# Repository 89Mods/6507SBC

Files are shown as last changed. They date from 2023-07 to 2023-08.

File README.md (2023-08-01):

# 6507SBC

A 6507-based single-board computer with 128 bytes RAM, 7KiB ROM, I/O, graphics and sound. As an added challenge, it was built with the requirement to not contain any IC larger than DIP-28.

`Hardware` contains the KiCad project files for the SBC itself, as well as the adapter board for the supported SPI peripherals.

`Programs` are programs written to test various features of the SBC.

`Verilog` contains a basic Verilog implementation of the 6507, and the pixel LCD peripheral. Used during software development when ROM swapping became too tedious. Doesn’t implement undocumented instructions or decimal mode.

For more information, see the writeup [on my website](https://tholin.dev/6507/).

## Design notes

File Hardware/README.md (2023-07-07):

# Hardware

Here are the KiCad projects for the computer! BOMs and Gerbers are in the respective 'production' folder of each KiCad project.

The 'expansion board' is a board that plugs directly into a header on the SBC, and adapts some of its I/O ports to two supported SPI peripherals, which can then be driven in software. One is a 25Qxx flash ROM for additional data storage (7KiB isn’t a lot), and the other a pixel LCD (ST7565), which forms the graphics output of the computer.

They can be found for cheap on AliExpress. I got [this one](https://aliexpress.com/item/1005001621784395.html).

However, in the absence of this, the SBC also has a header for a regular character LCD. If this is not required, components J5, RV1 and R19 can be omitted.

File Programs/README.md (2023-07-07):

# Programs

Here are various programs to test the computer’s hardware, and stress the CPU and Memory (mandelbrot renderer). Due to the memory map of the system, the ROM binaries must be padded with 1024 bytes of 0s at the beginning. The PadROM script written in Java takes care of this.

Every program is contained in its own directory, which also contains a bash script to automatically run all the commands to build the program. cc65 is required to assemble the programs.

<table>
    <tr>
        <th>Name</th>
        <th>Description</th>
    </tr>
    <tr>
        <td>board_test</td>
        <td>Just blinks some LEDs, makes beepboops and puts text on the character LCD.</td>
    </tr>
    <tr>
        <td>mandel</td>
        <td>Mandelbrot set renderer. Makes use of the pixel LCD.</td>
    </tr>
    <tr>
        <td>psg_test</td>
        <td>Tests the sound output by playing some tunes.</td>
    </tr>
    <tr>
        <td>spi_lcd_test</td>
        <td>Copies a bitmap image onto the SPI LCD for testing purposes.</td>
    </tr>
    <tr>
        <td>spi_rom_test</td>
        <td>Plays a VGM file from the SPI ROM. Code is a bit of a mess due to containing dummy subroutines to make the timing of the notes work out.</td>
    </tr>
</table>

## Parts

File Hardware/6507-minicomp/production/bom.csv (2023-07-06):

Designator | Footprint | Quantity | Value | LCSC Part #
BZ1 | Buzzer_12x9.5RM7.6 | 1 | Piezo Speaker
C1, C2, C3, C4 | CP_Radial_D6.3mm_P2.50mm | 4 | 10µF
D1, D2, D3 | D_A-405_P7.62mm_Horizontal | 3 | D
D4, D5, D6, D7 | LED_D3.0mm | 4 | LED
J1 | TerminalBlock_bornier-2_P5.08mm | 1 | Screw_Terminal_01x02
J2 | PinHeader_1x08_P2.54mm_Vertical | 1 | Conn_01x08_Female
J3 | PinHeader_1x11_P2.54mm_Vertical | 1 | Conn_01x11
J5 | PinHeader_1x16_P2.54mm_Vertical | 1 | Conn_01x16_Female
R1, R4, R7 | R_Axial_DIN0204_L3.6mm_D1.6mm_P7.62mm_Horizontal | 3 | 10K
R10, R11, R12, R14, R15, R16, R2, R3, R8, R9 | R_Axial_DIN0204_L3.6mm_D1.6mm_P7.62mm_Horizontal | 10 | 7.2K
R13, R17, R18 | R_Axial_DIN0204_L3.6mm_D1.6mm_P7.62mm_Horizontal | 3 | 4.7K
R19 | R_Axial_DIN0204_L3.6mm_D1.6mm_P7.62mm_Horizontal | 1 | 1K
R5 | R_Axial_DIN0204_L3.6mm_D1.6mm_P7.62mm_Horizontal | 1 | 200K
R6 | R_Axial_DIN0204_L3.6mm_D1.6mm_P7.62mm_Horizontal | 1 | 100
RV1 | Potentiometer_ACP_CA9-V10_Vertical | 1 | 10K
SW1, SW2 | SW_PUSH_6mm | 2 | SW_Push
U1, U2 | DIP-14_W7.62mm | 2 | 74LS08
U10, U11, U12 | DIP-24_W15.24mm | 3 | DS8212D
U3 | DIP-14_W7.62mm | 1 | 74HC04
U4 | DIP-28_W15.24mm | 1 | 6507
U5 | DIP-16_W7.62mm | 1 | 74LS163
U6 | DIP-8_W7.62mm | 1 | LM358
U7 | DIP-16_W7.62mm | 1 | SN76489
U8 | DIP-24_W15.24mm | 1 | MCM6810
U9 | DIP-28_W15.24mm | 1 | 28C256
X1 | Oscillator_DIP-14 | 1 | ACO-16.0MHz

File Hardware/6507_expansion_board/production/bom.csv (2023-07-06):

Designator | Footprint | Quantity | Value | LCSC Part #
C1 | 1206 | 1 | 100nF
C2 | 1206 | 1 | 100nF
D1 | 0805 | 1 | LED
D2 | 0805 | 1 | D
J1 | PinHeader_1x11_P2.54mm_Vertical | 1 | Conn_01x11
J2 | PinHeader_1x13_P2.54mm_Vertical | 1 | Conn_01x13
R1 | 2010 | 1 | 1K
R10 | 2010 | 1 | 1K
R11 | 2010 | 1 | 1K
R12 | 2010 | 1 | 1K
R13 | 2010 | 1 | 1K
R14 | 2010 | 1 | 1K
R2 | 2010 | 1 | 1K
R3 | 2010 | 1 | 1K
R4 | 2010 | 1 | 1K
R6 | 2010 | 1 | 1K
R7 | 2010 | 1 | 1K
R8 | 2010 | 1 | 1K
R9 | 2010 | 1 | 1K
U1 | DIP-8_W7.62mm_LongPads | 1 | MX25L1005
U2 | SOT-223-3_TabPin2 | 1 | AMS1117

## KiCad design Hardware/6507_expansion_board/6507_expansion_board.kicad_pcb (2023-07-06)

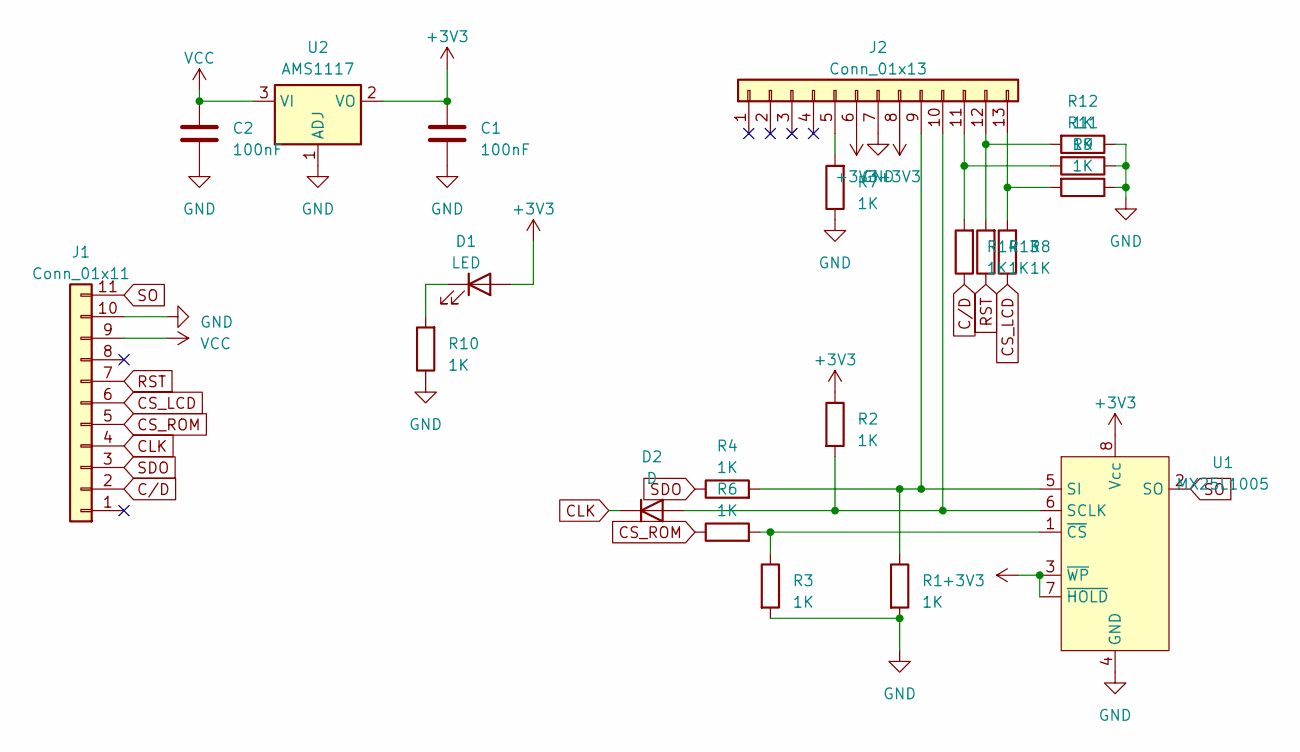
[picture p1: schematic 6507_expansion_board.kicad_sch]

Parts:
C1, C2: 100nF; C_1206_3216Metric
D1: LED; LED_0805_2012Metric
D2: D; D_0805_2012Metric
J1: Conn_01x11; PinHeader_1x11_P2.54mm_Vertical
J2: Conn_01x13; PinHeader_1x13_P2.54mm_Vertical
R1, R2, R3, R4, R6, R7, R8, R9, R10, R11, R12, R13, R14: 1K; R_2010_5025Metric_Pad1.40x2.65mm_HandSolder
U1: MX25L1005; DIP-8_W7.62mm_LongPads
U2: AMS1117; SOT-223-3_TabPin2

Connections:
+3V3: C1.1, D1.2 (A), J2.6, J2.8, R2.1, U1.3 (~WP), U1.7 (~HOLD), U1.8 (Vcc), U2.2 (VO)
CLK: D2.1 (K), J1.4
CS_LCD: J1.6, R8.1
CS_ROM: J1.5, R6.1
C/D: J1.2, R14.1
GND: C1.2, C2.2, J1.10, J2.7, R1.2, R3.2, R7.1, R9.1, R10.1, R11.1, R12.1, U1.4 (GND), U2.1 (ADJ)
unnamed: D1.1 (K), R10.2
unnamed: D2.2 (A), J2.10, R2.2, U1.6 (SCLK)
unnamed: J2.5, R7.2
unnamed: J2.9, R1.1, R4.2, U1.5 (SI)
unnamed: J2.11, R11.2, R14.2
unnamed: J2.12, R12.2, R13.2
unnamed: J2.13, R8.2, R9.2
unnamed: R3.1, R6.2, U1.1 (~CS)
RST: J1.7, R13.1
SDO: J1.3, R4.1
SO: J1.11, U1.2 (SO)
VCC: C2.1, J1.9, U2.3 (VI)

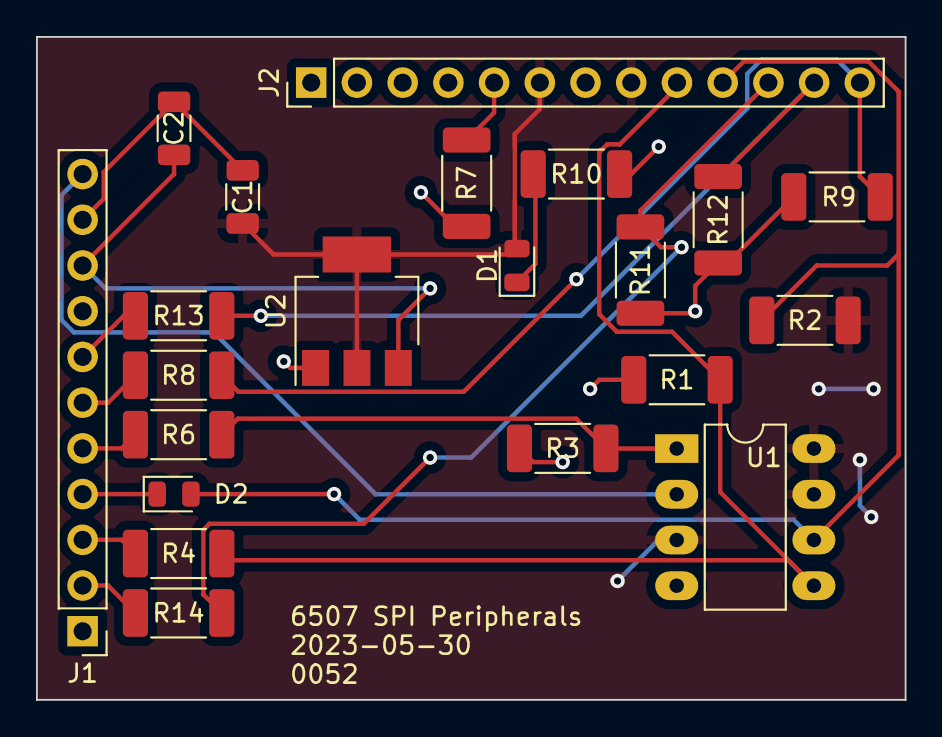
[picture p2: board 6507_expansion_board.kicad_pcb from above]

Board: 2 copper layers, 48.3 x 36.8 mm, 21 parts (0 on the bottom side), 18 nets.

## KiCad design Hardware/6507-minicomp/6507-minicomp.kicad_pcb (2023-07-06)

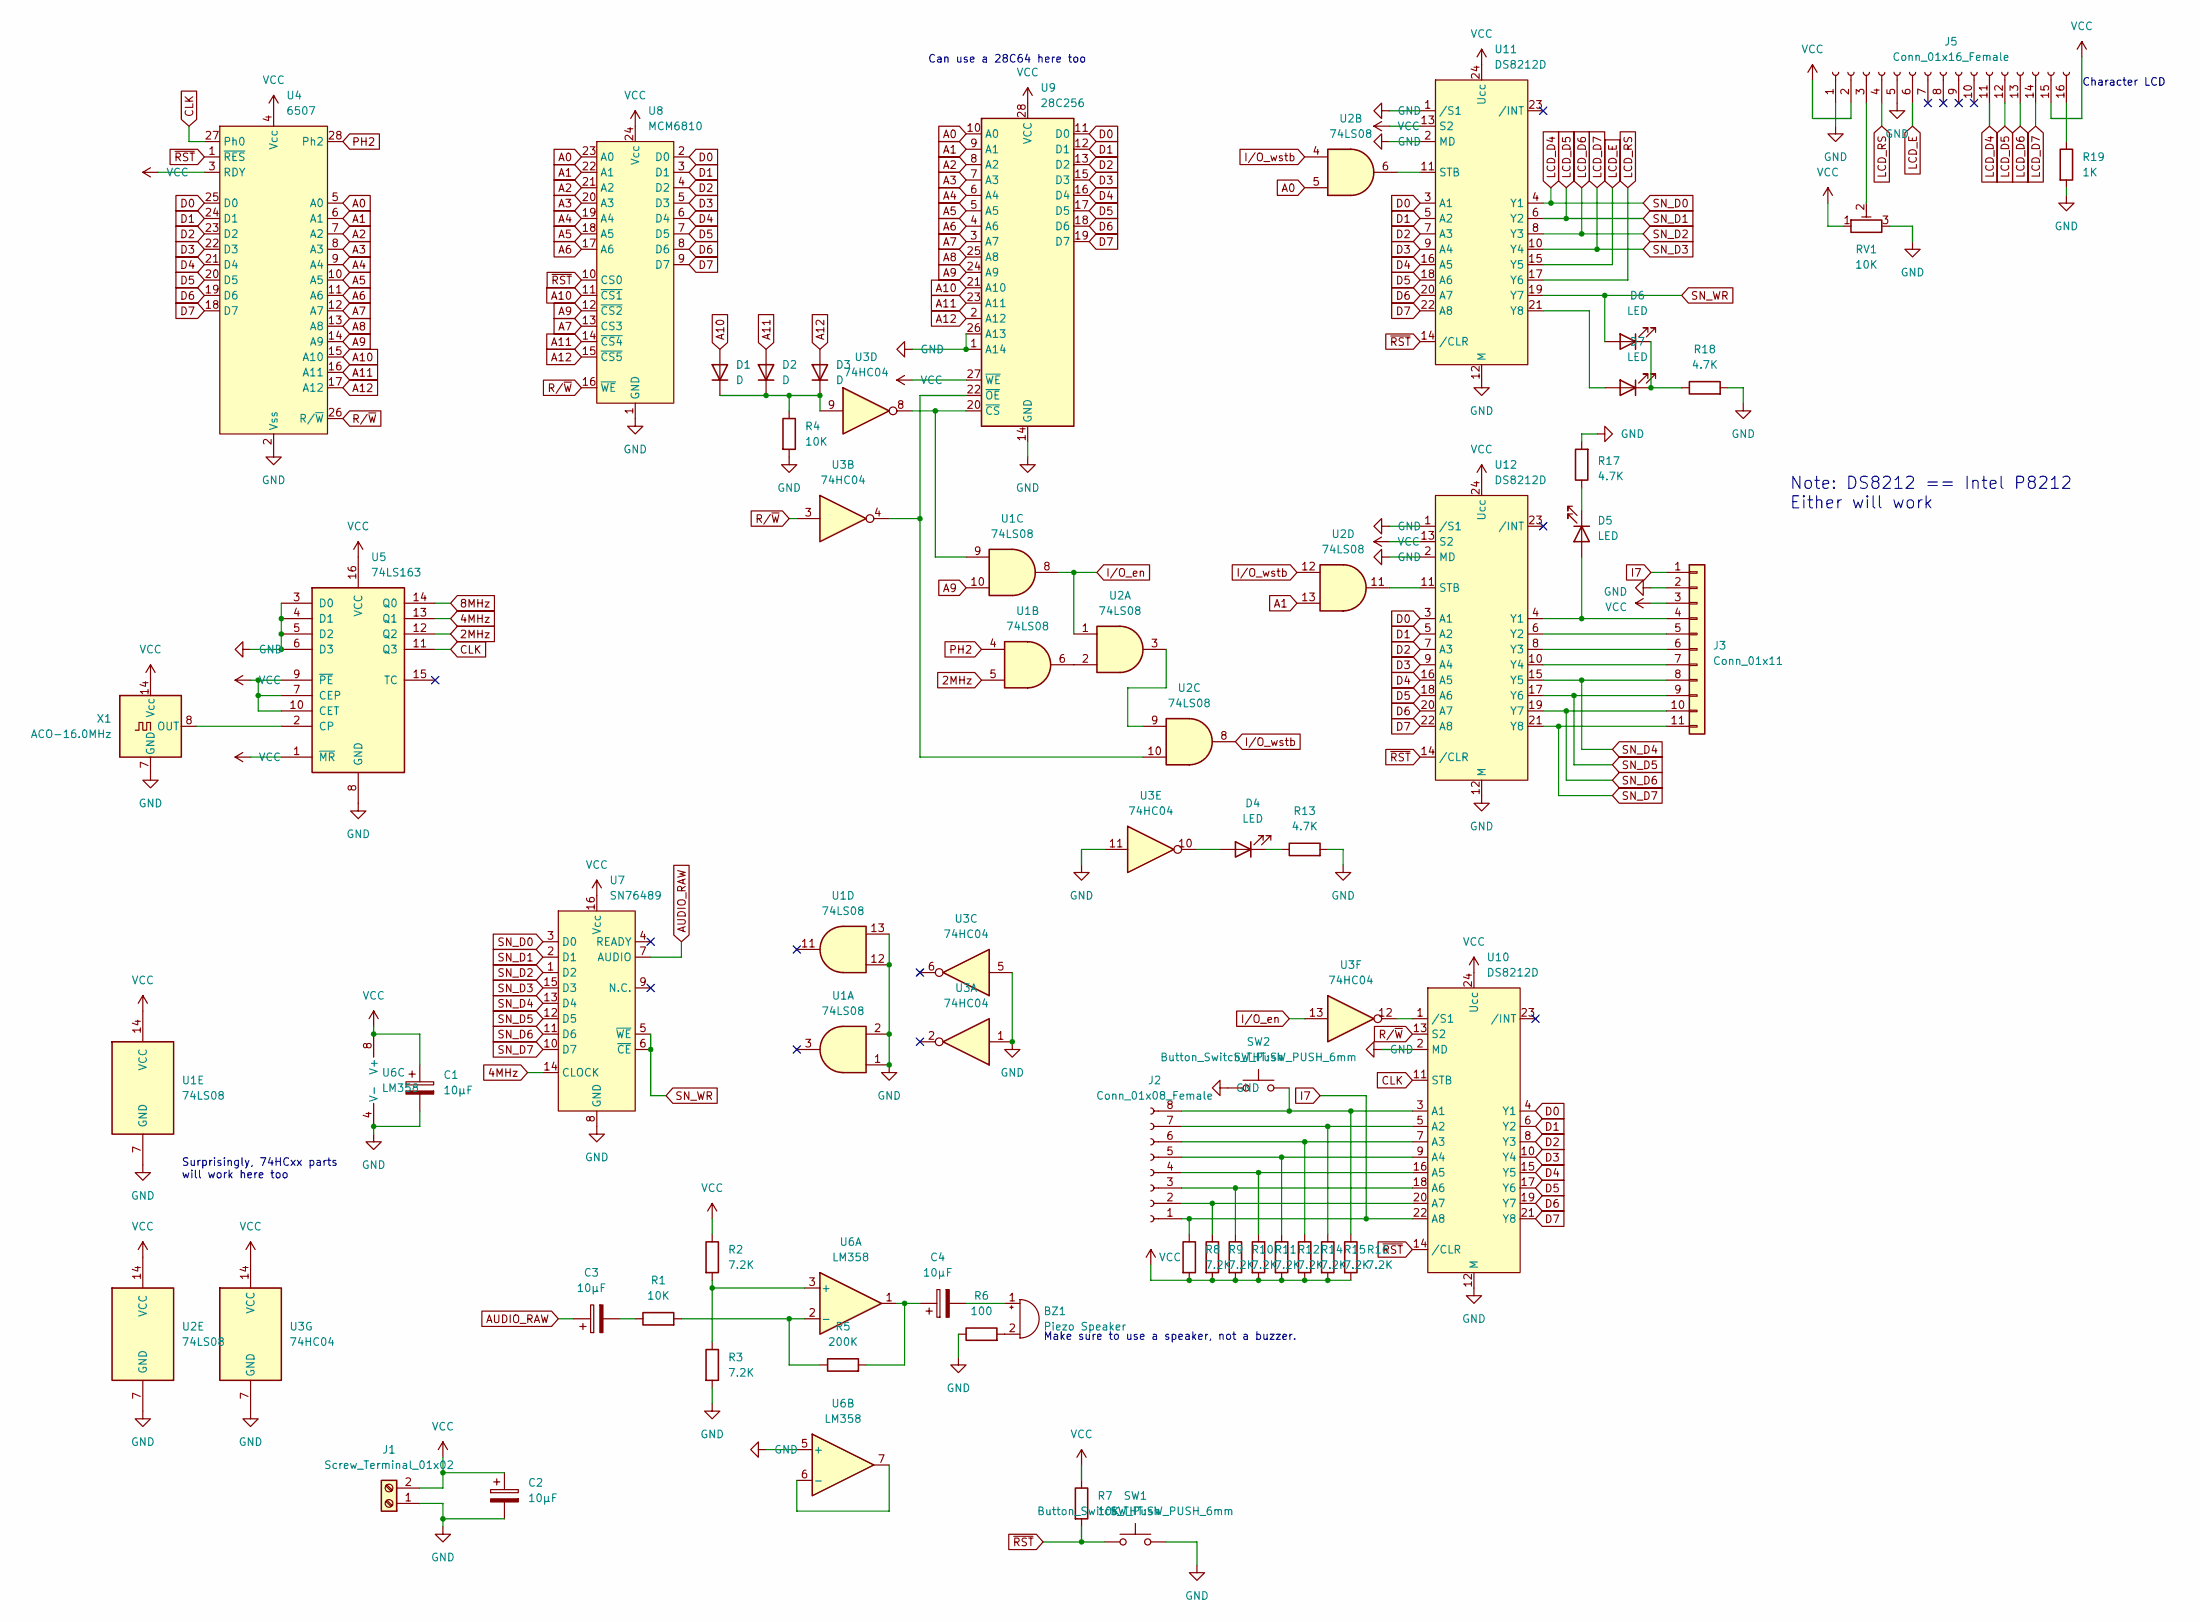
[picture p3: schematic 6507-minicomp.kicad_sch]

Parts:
BZ1: Piezo Speaker; Buzzer_12x9.5RM7.6
C1, C2, C3, C4: 10µF; CP_Radial_D6.3mm_P2.50mm
D1, D2, D3: D; D_A-405_P7.62mm_Horizontal
D4, D5, D6, D7: LED; LED_D3.0mm
J1: Screw_Terminal_01x02; TerminalBlock_bornier-2_P5.08mm
J2: Conn_01x08_Female; PinHeader_1x08_P2.54mm_Vertical
J3: Conn_01x11; PinHeader_1x11_P2.54mm_Vertical
J5: Conn_01x16_Female; PinHeader_1x16_P2.54mm_Vertical
R1, R4, R7: 10K; R_Axial_DIN0204_L3.6mm_D1.6mm_P7.62mm_Horizontal
R2, R3, R8, R9, R10, R11, R12, R14, R15, R16: 7.2K; R_Axial_DIN0204_L3.6mm_D1.6mm_P7.62mm_Horizontal
R5: 200K; R_Axial_DIN0204_L3.6mm_D1.6mm_P7.62mm_Horizontal
R6: 100; R_Axial_DIN0204_L3.6mm_D1.6mm_P7.62mm_Horizontal
R13, R17, R18: 4.7K; R_Axial_DIN0204_L3.6mm_D1.6mm_P7.62mm_Horizontal
R19: 1K; R_Axial_DIN0204_L3.6mm_D1.6mm_P7.62mm_Horizontal
RV1: 10K; Potentiometer_ACP_CA9-V10_Vertical
SW1, SW2: SW_Push; SW_PUSH_6mm
U1, U2: 74LS08; DIP-14_W7.62mm
U3: 74HC04; DIP-14_W7.62mm
U4: 6507; DIP-28_W15.24mm
U5: 74LS163; DIP-16_W7.62mm
U6: LM358; DIP-8_W7.62mm
U7: SN76489; DIP-16_W7.62mm
U8: MCM6810; DIP-24_W15.24mm
U9: 28C256; DIP-28_W15.24mm
U10, U11, U12: DS8212D; DIP-24_W15.24mm
X1: ACO-16.0MHz; Oscillator_DIP-14

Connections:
2MHz: U1.5, U5.12 (Q2)
4MHz: U5.13 (Q1), U7.14 (CLOCK)
8MHz: U5.14 (Q0)
A0: U2.5, U4.5 (A0), U8.23 (A0), U9.10 (A0)
A1: U2.13, U4.6 (A1), U8.22 (A1), U9.9 (A1)
A2: U4.7 (A2), U8.21 (A2), U9.8 (A2)
A3: U4.8 (A3), U8.20 (A3), U9.7 (A3)
A4: U4.9 (A4), U8.19 (A4), U9.6 (A4)
A5: U4.10 (A5), U8.18 (A5), U9.5 (A5)
A6: U4.11 (A6), U8.17 (A6), U9.4 (A6)
A7: U4.12 (A7), U8.13 (CS3), U9.3 (A7)
A8: U4.13 (A8), U9.25 (A8)
A9: U1.10, U4.14 (A9), U8.12 (~CS2), U9.24 (A9)
A10: D1.2 (A), U4.15 (A10), U8.11 (~CS1), U9.21 (A10)
A11: D2.2 (A), U4.16 (A11), U8.14 (~CS4), U9.23 (A11)
A12: D3.2 (A), U4.17 (A12), U8.15 (~CS5), U9.2 (A12)
AUDIO_RAW: C3.1, U7.7 (AUDIO)
CLK: U4.27 (Ph0), U5.11 (Q3), U10.11 (STB)
D0: U4.25 (D0), U8.2 (D0), U9.11 (D0), U10.4 (Y1), U11.3 (A1), U12.3 (A1)
D1: U4.24 (D1), U8.3 (D1), U9.12 (D1), U10.6 (Y2), U11.5 (A2), U12.5 (A2)
D2: U4.23 (D2), U8.4 (D2), U9.13 (D2), U10.8 (Y3), U11.7 (A3), U12.7 (A3)
D3: U4.22 (D3), U8.5 (D3), U9.15 (D3), U10.10 (Y4), U11.9 (A4), U12.9 (A4)
D4: U4.21 (D4), U8.6 (D4), U9.16 (D4), U10.15 (Y5), U11.16 (A5), U12.16 (A5)
D5: U4.20 (D5), U8.7 (D5), U9.17 (D5), U10.17 (Y6), U11.18 (A6), U12.18 (A6)
D6: U4.19 (D6), U8.8 (D6), U9.18 (D6), U10.19 (Y7), U11.20 (A7), U12.20 (A7)
D7: U4.18 (D7), U8.9 (D7), U9.19 (D7), U10.21 (Y8), U11.22 (A8), U12.22 (A8)
GND: C1.2, C2.2, J1.1, J3.2, J5.1, J5.5, R3.2, R4.2, R6.1, R13.2, R17.2, R18.2, R19.2, RV1.3, SW1.2, SW2.1, U1.1, U1.2, U1.7 (GND), U1.12, U1.13, U2.7 (GND), U3.1, U3.5, U3.7 (GND), U3.11, U4.2 (Vss), U5.3 (D0), U5.4 (D1), U5.5 (D2), U5.6 (D3), U5.8 (GND), U6.4 (V-), U6.5 (+), U7.8 (GND), U8.1 (GND), U9.1 (A14), U9.14 (GND), U9.26 (A13), U10.2 (MD), U10.12 (M), U11.1 (/S1), U11.2 (MD), U11.12 (M), U12.1 (/S1), U12.2 (MD), U12.12 (M), X1.7 (GND)
I7: J2.1, J3.1, R8.1, U10.22 (A8)
I/O_en: U1.8, U2.1, U3.13
I/O_wstb: U2.4, U2.8, U2.12
LCD_D4: J5.11, U7.3 (D0), U11.4 (Y1)
LCD_D5: J5.12, U7.2 (D1), U11.6 (Y2)
LCD_D6: J5.13, U7.1 (D2), U11.8 (Y3)
LCD_D7: J5.14, U7.15 (D3), U11.10 (Y4)
LCD_E: J5.6, U11.15 (Y5)
LCD_RS: J5.4, U11.17 (Y6)
unnamed: BZ1.2 (+), R6.2
unnamed: BZ1.1 (-), C4.2
unnamed: C3.2, R1.1
unnamed: C4.1, R5.2, U6.1
unnamed: D1.1 (K), D2.1 (K), D3.1 (K), R4.1, U3.9
unnamed: D4.2 (A), U3.10
unnamed: D4.1 (K), R13.1
unnamed: D5.2 (A), J3.4, U12.4 (Y1)
unnamed: D5.1 (K), R17.1
unnamed: D6.1 (K), D7.1 (K), R18.1
unnamed: D7.2 (A), U11.21 (Y8)
unnamed: J2.2, R9.1, U10.20 (A7)
unnamed: J2.3, R10.1, U10.18 (A6)
unnamed: J2.4, R11.1, U10.16 (A5)
unnamed: J2.5, R12.1, U10.9 (A4)
unnamed: J2.6, R14.1, U10.7 (A3)
unnamed: J2.7, R15.1, U10.5 (A2)
unnamed: J2.8, R16.1, SW2.2, U10.3 (A1)
unnamed: J3.5, U12.6 (Y2)
unnamed: J3.6, U12.8 (Y3)
unnamed: J3.7, U12.10 (Y4)
unnamed: J5.3, RV1.2
unnamed: J5.16, R19.1
unnamed: U1.6, U2.2
unnamed: U2.3, U2.9
unnamed: U5.2 (CP), X1.8 (OUT)
unnamed: R2.2, R3.1, U6.3 (+)
unnamed: R1.2, R5.1, U6.2 (-)
unnamed: U6.6 (-), U6.7
unnamed: U1.9, U3.8, U9.20 (~CS)
unnamed: U2.10, U3.4, U9.22 (~OE)
unnamed: U3.12, U10.1 (/S1)
unnamed: U2.6, U11.11 (STB)
unnamed: U2.11, U12.11 (STB)
PH2: U1.4, U4.28 (Ph2)
R/~W: U3.3, U4.26 (R/~W), U8.16 (~WE), U10.13 (S2)
SN_D4: J3.8, U7.13 (D4), U12.15 (Y5)
SN_D5: J3.9, U7.12 (D5), U12.17 (Y6)
SN_D6: J3.10, U7.11 (D6), U12.19 (Y7)
SN_D7: J3.11, U7.10 (D7), U12.21 (Y8)
SN_WR: D6.2 (A), U7.5 (~WE), U7.6 (~CE), U11.19 (Y7)
VCC: C1.1, C2.1, J1.2, J3.3, J5.2, J5.15, R2.1, R7.1, R8.2, R9.2, R10.2, R11.2, R12.2, R14.2, R15.2, R16.2, RV1.1, U1.14 (VCC), U2.14 (VCC), U3.14 (VCC), U4.3 (RDY), U4.4 (Vcc), U5.1 (~MR), U5.7 (CEP), U5.9 (~PE), U5.10 (CET), U5.16 (VCC), U6.8 (V+), U7.16 (Vcc), U8.24 (Vcc), U9.27 (~WE), U9.28 (VCC), U10.24 (Ucc), U11.13 (S2), U11.24 (Ucc), U12.13 (S2), U12.24 (Ucc), X1.14 (Vcc)
~RST: R7.2, SW1.1, U4.1 (~RES), U8.10 (CS0), U10.14 (/CLR), U11.14 (/CLR), U12.14 (/CLR)

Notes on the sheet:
Character LCD
Make sure to use a speaker, not a buzzer.
Note: DS8212 == Intel P8212 Either will work
Surprisingly, 74HCxx parts will work here too
Can use a 28C64 here too

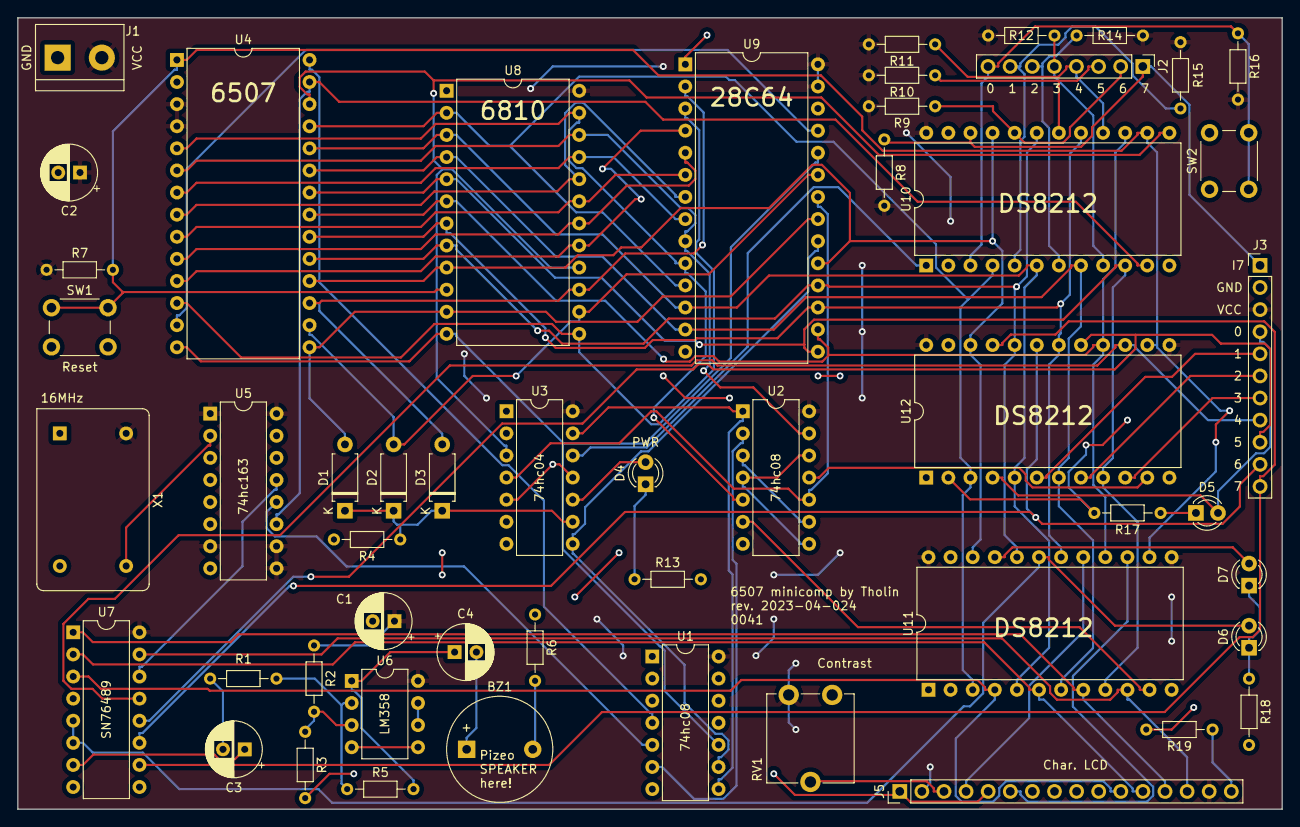
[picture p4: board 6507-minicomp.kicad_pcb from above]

Board: 2 copper layers, 145.3 x 90.9 mm, 51 parts (0 on the bottom side), 78 nets.

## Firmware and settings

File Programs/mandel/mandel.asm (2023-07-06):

.feature string_escapes
.feature org_per_seg
.feature c_comments

PORT1_OUT  = $0201
PORT2_OUT  = $0202
PORT_IN    = $0208

mem_start = $80
port1_shadow = mem_start+1
port2_shadow = mem_start+2
counter = mem_start+6
temp0 = mem_start+7
temp1 = mem_start+8

min00 = mem_start+9
min01 = mem_start+10
min02 = mem_start+11
min03 = mem_start+12
min10 = mem_start+13
min11 = mem_start+14
min12 = mem_start+15
min13 = mem_start+16
mres0 = mem_start+17
mres1 = mem_start+18
mres2 = mem_start+19
mres3 = mem_start+20
mres4 = mem_start+21
mres5 = mem_start+22
mres6 = mem_start+23
mres7 = mem_start+24
mtemp0 = mem_start+25
mtemp1 = mem_start+26
mtemp2 = mem_start+27
mtemp3 = mem_start+28
mtemp4 = mem_start+29
mtemp5 = mem_start+30
mtemp6 = mem_start+31

loopi0 = mem_start+32
loopi1 = mem_start+33
col_buff = mem_start+34
xpos = mem_start+35
ypos = mem_start+36

; Mandel vars
C1 = mem_start+40
C2 = mem_start+44
C3 = mem_start+48
C4 = mem_start+52
C_IM = mem_start+56
C_RE = mem_start+60
MAN_X = mem_start+64
MAN_Y = mem_start+68
MAN_XX = mem_start+72
MAN_YY = mem_start+76
ITERATION = mem_start+80

rem0 = mem_start+81
rem1 = mem_start+82
rem2 = mem_start+83
rem3 = mem_start+84

width = 128
height = 64
total_loops = 8192

; Constants
W_D2 = 64
H_D2 = 32

ZOOM = 16000000
RE = 0
IMAG = 0
MAX_ITER = 128

.segment "CODE"
NMI:
	rti
IRQ:
	rti
RESET:
	ldx #$FF
	txs
	lda #0
	sta mem_start
	cld
	clv
	
	lda #%00001100
	sta PORT2_OUT
	sta port2_shadow
	
	lda #%01010000
	sta PORT1_OUT
	sta port1_shadow
	jsr init_psg
	jsr reset_lcd
	
	jsr clear_lcd
	jsr lcd_select
	
mandel_calc_constants_c1:
	; res = 4 / width
	lda #0
	sta min00
	sta min01
	sta min02
	lda #4
	sta min03
	lda #0
	sta min10
	sta min11
	sta min12
	lda #width
	sta min13
	jsr div_fixed
	; C1 = res * ZOOM
	lda mres0
	sta min00
	lda mres1
	sta min01
	lda mres2
	sta min02
	lda mres3
	sta min03
	lda #ZOOM&255
	sta min10
	lda #(ZOOM>>8)&255
	sta min11
	lda #(ZOOM>>16)&255
	sta min12
	lda #(ZOOM>>24)&255
	sta min13
	jsr mul_fixed
	lda mres0
	sta C1
	sta min10
	lda mres1
	sta C1+1
	sta min11
	lda mres2
	sta C1+2
	sta min12
	lda mres3
	sta C1+3
	sta min13
	; C2 = W_D2 * C1
	lda #0
	sta min00
	sta min01
	sta min02
	lda #W_D2
	sta min03
	jsr mul_fixed
	lda mres0
	sta C2
	lda mres1
	sta C2+1
	lda mres2
	sta C2+2
	lda mres3
	sta C2+3
	
mandel_calc_constants_c4:
	; res = 2 / height
	lda #0
	sta min00
	sta min01
	sta min02
	lda #2
	sta min03
	lda #0
	sta min10
	sta min11
	sta min12
	lda #height
	sta min13
	jsr div_fixed
	; C4 = res * ZOOM
	lda mres0
	sta min00
	lda mres1
	sta min01
	lda mres2
	sta min02
	lda mres3
	sta min03
	lda #ZOOM&255
	sta min10
	lda #(ZOOM>>8)&255
	sta min11
	lda #(ZOOM>>16)&255
	sta min12
	lda #(ZOOM>>24)&255
	sta min13
	jsr mul_fixed
	lda mres0
	sta C4
	sta min10
	lda mres1
	sta C4+1
	sta min11
	lda mres2
	sta C4+2
	sta min12
	lda mres3
	sta C4+3
	sta min13
	; C3 = H_D2 * C4
	lda #0
	sta min00
	sta min01
	sta min02
	lda #H_D2
	sta min03
	jsr mul_fixed
	lda mres0
	sta C3
	lda mres1
	sta C3+1
	lda mres2
	sta C3+2
	lda mres3
	sta C3+3
	
	lda #0
	sta loopi0
	sta loopi1
	lda #7
	sta ypos
	jsr lcd_sety
	lda #width
	sta xpos
mandel_loop_main:
	jsr lcd_unselect
	nop
	nop
	nop
	nop
	nop
	nop
	nop
	nop
	jsr lcd_select
	nop
	nop
	nop
	nop
	nop
	nop
	nop
	nop
	lda loopi0
	and #7
	beq col_loop_done
	jmp col_loop_not_done
col_loop_done:
	lda xpos
	jsr lcd_setx
	lda col_buff
	jsr lcd_data
	
	dec xpos
	lda #255
	cmp xpos
	bne not_at_end_of_row
	jsr lcd_unselect
	nop
	nop
	nop
	nop
	jsr boop
	jsr lcd_select
	nop
	nop
	nop
	nop
	lda #width-1
	sta xpos
	jsr lcd_setx
	dec ypos
	lda ypos
	jsr lcd_sety
not_at_end_of_row:
	lda xpos
	jsr lcd_setx
	lda #0
	sta col_buff
	
	; Recompute C_RE
	; res = col * C1
	lda #0
	sta min00
	sta min01
	sta min02
	lda xpos
	eor #127
	sta min03
	lda C1
	sta min10
	lda C1+1
	sta min11
	lda C1+2
	sta min12
	lda C1+3
	sta min13
	jsr mul_fixed
	; res = res + RE
	clc
	lda mres0
	adc #RE&255
	sta mres0
	lda mres1
	adc #(RE>>8)&255
	sta mres1
	lda mres2
	adc #(RE>>16)&255
	sta mres2
	lda mres3
	adc #(RE>>24)&255
	sta mres3
	; C_RE = res - C2
	sec
	lda mres0
	sbc C2
	sta C_RE
	lda mres1
	sbc C2+1
	sta C_RE+1
	lda mres2
	sbc C2+2
	sta C_RE+2
	lda mres3
	sbc C2+3
	sta C_RE+3
	
col_loop_not_done:
	lda xpos
	jsr lcd_setx
	lda ypos
	jsr lcd_sety
	lda loopi0
	and #7
	tax
	lda col_buff
	ora bit_mask,X
	jsr lcd_data
	
	; Compute C_IM
	; res = row * C4
	lda #0
	sta min00
	sta min01
	sta min02
	
	lda ypos
	eor #7
	asl
	asl
	asl
	sta temp0
	lda loopi0
	and #7
	clc
	adc temp0
	sta min03
	
	lda C4
	sta min10
	lda C4+1
	sta min11
	lda C4+2
	sta min12
	lda C4+3
	sta min13
	jsr mul_fixed
	; res = res + IMAG
	clc
	lda mres0
	adc #IMAG&255
	sta mres0
	lda mres1
	adc #(IMAG>>8)&255
	sta mres1
	lda mres2
	adc #(IMAG>>16)&255
	sta mres2
	lda mres3
	adc #(IMAG>>24)&255
	sta mres3
	; C_IM = Y = res - C3
	sec
	lda mres0
	sbc C3
	sta C_IM
	STA MAN_Y
	lda mres1
	sbc C3+1
	sta C_IM+1
	sta MAN_Y+1
	lda mres2
	sbc C3+2
	sta C_IM+2
	sta MAN_Y+2
	lda mres3
	sbc C3+3
	sta C_IM+3
	sta MAN_Y+3
	
	; X = c_re
	lda C_RE
	sta MAN_X
	lda C_RE+1
	sta MAN_X+1
	lda C_RE+2
	sta MAN_X+2
	lda C_RE+3
	sta MAN_X+3
	
	; iteration = 0
	lda #0
	sta ITERATION
	sta ITERATION+1
mandel_calc_loop:
	; yy = y * y
	lda MAN_Y
	sta min00
	sta min10
	lda MAN_Y+1
	sta min01
	sta min11
	lda MAN_Y+2
	sta min02
	sta min12
	lda MAN_Y+3
	sta min03
	sta min13
	jsr mul_fixed
	lda mres0
	sta MAN_YY
	lda mres1
	sta MAN_YY+1
	lda mres2
	sta MAN_YY+2
	lda mres3
	sta MAN_YY+3
	; res = x * y
	lda MAN_X
	sta min00
	lda MAN_X+1
	sta min01
	lda MAN_X+2
	sta min02
	lda MAN_X+3
	sta min03
	lda MAN_Y
	sta min10
	lda MAN_Y+1
	sta min11
	lda MAN_Y+2
	sta min12
	lda MAN_Y+3
	sta min13
	jsr mul_fixed
	; res = res << 1
	asl mres0
	rol mres1
	rol mres2
	rol mres3
	; Y = res + c_im
	clc
	lda mres0
	adc C_IM
	sta MAN_Y
	lda mres1
	adc C_IM+1
	sta MAN_Y+1
	lda mres2
	adc C_IM+2
	sta MAN_Y+2
	lda mres3
	adc C_IM+3
	sta MAN_Y+3
	; res = X * X
	lda MAN_X
	sta min00
	sta min10
	lda MAN_X+1
	sta min01
	sta min11
	lda MAN_X+2
	sta min02
	sta min12
	lda MAN_X+3
	sta min03
	sta min13
	jsr mul_fixed
	; XX = res
	; res = res - YY
	sec
	lda mres0
	sta MAN_XX
	sbc MAN_YY
	sta mres0
	lda mres1
	sta MAN_XX+1
	sbc MAN_YY+1
	sta mres1
	lda mres2
	sta MAN_XX+2
	sbc MAN_YY+2
	sta mres2
	lda mres3
	sta MAN_XX+3
	sbc MAN_YY+3
	sta mres3
	; X = res + C_RE
	clc
	lda mres0
	adc C_RE
	sta MAN_X
	lda mres1
	adc C_RE+1
	sta MAN_X+1
	lda mres2
	adc C_RE+2
	sta MAN_X+2
	lda mres3
	adc C_RE+3
	sta MAN_X+3
	
	; check if xx + yy <= 4
	clc
	lda MAN_XX
	adc MAN_YY
	lda MAN_XX+1
	adc MAN_YY+1
	lda MAN_XX+2
	adc MAN_YY+2
	lda MAN_XX+3
	adc MAN_YY+3
	cmp #4
	bmi mandel_calc_continue
	jmp mandel_exit_overflow
mandel_calc_continue:
	sec
	lda ITERATION
	adc #0
	sta ITERATION
	lda ITERATION+1
	adc #0
	sta ITERATION+1
	
	lda ITERATION+1
	eor #(MAX_ITER>>8)&255
	bne mandel_calc_continue2
	lda ITERATION
	eor #MAX_ITER&255
	bne mandel_calc_continue2
	jmp mandel_exit_inside
mandel_calc_continue2:
	jmp mandel_calc_loop
mandel_exit_inside:
	sec
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

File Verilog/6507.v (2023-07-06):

`define FETCH 0
`define EXECUTE1 1
`define EXECUTE2 2
`define EXECUTE3 3
`define EXECUTE4 4
`define INDIRECT1 8
`define INDIRECT2 9
`define JSR1 10
`define JSR2 11
`define JSR3 12
`define RET1 13
`define RET2 14
`define RET3 15

module CPU_6507(
	output [12:0] addr_bus,
	output reg [7:0] d_out,
	input [7:0] d_in,
	output reg wenb,
	
	input clk,
	input rstb,
	input rdy
);

reg [7:0] A;
reg [7:0] X;
reg [7:0] Y;
reg carry;
reg intr_disable;
reg overflow;
reg decimal;
reg [7:0] stack_ptr;
reg negative;
reg zero;

reg [15:0] PC;
reg [15:0] full_addr;
assign addr_bus = full_addr[12:0];

reg [7:0] addr_in_buff;

reg [7:0] I;
reg is_reset;
reg [3:0] phase;

wire [7:0] instr = phase == `EXECUTE1 ? d_in : I;

// Decode logic
wire isNOP = instr == 8'hEA;

wire isLoadOrStore = instr[7:6] == 2'b10 && !isNOP && !(
		instr == 8'h90 ||
		instr == 8'hB0 ||
		instr[3:0] == 4'h8 ||
		instr[3:0] == 4'hA
	);
wire isLoad = isLoadOrStore && instr[5];
wire isStore = isLoadOrStore && !instr[5];

wire isJSR = instr == 8'h20;
wire isRTS = instr == 8'h60;
wire isRTI = instr == 8'h40;
wire isTransfer = instr == 8'h98 || instr == 8'hA8 || (instr[3:0] == 4'hA && instr[7:6] == 2'b10);
wire isBranch = instr[4:0] == 5'h10;
wire isJump = instr == 8'h4C || instr == 8'h6C;
wire isStack = ~instr[7] && instr[4:0] == 5'h08;
wire pull = instr[5];
wire isSpecial = (~instr[7] && instr[4:0] == 5'h18) || instr == 8'hB8 || instr == 8'hD8 || instr == 8'hF8;

wire isArith = !isLoadOrStore && !isNOP && !isTransfer && !isBranch && !isJump && !isTransfer && !isStack && !isSpecial;

wire isBreak = instr == 8'h00;

wire isImplied = instr[3:0] == 4'hA || instr[3:0] == 4'h8;
wire isImmediate = instr[4:0] == 5'h09 || instr[3:0] == 4'h02 || (instr[7] && ~instr[4] && instr[3:0] == 0); 
wire isIndexed = instr[4];
wire indexedByY = instr[3:0] == 4'h1 || instr[3:0] == 4'h9 || instr == 8'h96 || instr == 8'hB6 || instr == 8'hBE;
wire indexedIndirect = instr[4:0] == 5'h01;
wire indirectIndexed = instr[4:0] == 5'h11;
wire zeropage = (indexedIndirect || indirectIndexed || instr[3:2] == 2'b01) && !isImplied;
wire addr16 = !isImmediate && (instr[3:0] == 4'h9 || instr[3:2] == 2'b11 || instr == 8'h20) && !isImplied;
wire isCompare = (instr[7:5] == 3'b110 && instr[1:0] == 2'b01) || instr[3:0] == 4'h4 || instr[3:0] == 4'h0 || instr[3:0] == 4'hC;
wire isBit = instr == 8'h2C || instr == 8'h24;

// ALU
wire [7:0] ALU_in1 = ~instr[0] && instr[3:0] != 4'hA && ~instr[7] ? d_in : ( //Shifts and rotates
		instr[7] && instr[1:0] == 2'b00 ? (instr[5] ? X : Y) : (
		instr[7] && instr[1:0] == 2'b01 ? A : (
		(instr[7] && instr[1:0] == 2'b10 && instr != 8'hCA) || isBit ? d_in : (
		instr == 8'hCA ? X : (instr == 8'h88 ? Y : A)
	))));
wire [7:0] ALU_in2 = d_in;
wire [7:0] ALU_nin2 = ~d_in;
reg [8:0] ALU_res;

wire [7:0] ALU_sub = ALU_in1 - ALU_in2;
wire [7:0] ALU_sbc = ALU_sub - !carry;

wire [3:0] ALU_opsel = {instr[0], instr[7:5]};
always @(*) begin
	case(ALU_opsel)
		0: ALU_res <= {ALU_in1, 1'b0};
		1: ALU_res <= {ALU_in1, carry};
		2: ALU_res <= {ALU_in1[0], 1'b0, ALU_in1[7:1]};
		3: ALU_res <= {ALU_in1[0], carry, ALU_in1[7:1]};
		4: ALU_res <= {carry, ALU_in1 - 1'b1};
		5: ALU_res <= {carry, ALU_in1};
		6: ALU_res <= instr == 8'hC8 ? {carry, ALU_in1 + 1'b1} : {carry, ALU_in1 - 1'b1};
		7: ALU_res <= {carry, ALU_in1 + 1'b1};
		8: ALU_res <= {carry, ALU_in1 | ALU_in2};
		9: ALU_res <= {carry, ALU_in1 & ALU_in2};
		10: ALU_res <= {carry, ALU_in1 ^ ALU_in2};
		11: ALU_res <= ALU_in1 + ALU_in2 + carry;
		12: ALU_res <= {carry, ALU_in1};
		13: ALU_res <= {carry, ALU_in1};
		14: ALU_res <= ALU_in1 + ALU_nin2 + 1'b1;
		15: ALU_res <= ALU_in1 + ALU_nin2 + carry;
	endcase
end

wire toA = !isLoadOrStore && !isCompare && (
		instr[3:0] == 4'h1 ||
		instr[3:0] == 4'h5 ||
		instr[3:0] == 4'h9 ||
		(instr[3:0] == 4'hA && ~instr[7]) ||
		instr[3:0] == 4'hD
	);
wire toY = instr == 8'hC8 || instr == 8'h88;
wire toX = instr == 8'hE8 || instr == 8'hCA;
wire toMem = (instr[3:0] == 4'hE || instr[3:0] == 4'h6) && !isLoadOrStore;

wire loadstoreTargetA = instr[1:0] == 2'b01;
wire loadstoreTargetX = instr[1:0] == 2'b10;
wire loadstoreTargetY = instr[1:0] == 2'b00;

wire [7:0] status_word = {negative, overflow, 1'b0, 1'b0, decimal, intr_disable, zero, carry};

//Branch conditions
reg should_branch;
always @(*) begin
	case(instr[7:5])
		0: should_branch <= negative == 1'b0;
		1: should_branch <= negative == 1'b1;
		2: should_branch <= overflow == 1'b0;
		3: should_branch <= overflow == 1'b1;
		4: should_branch <= carry == 1'b0;
		5: should_branch <= carry == 1'b1;
		6: should_branch <= zero == 1'b0;
		7: should_branch <= zero == 1'b1;
	endcase
end

wire [2:0] transfer_idx = {instr[1], instr[5:4]};

reg [7:0] transfer_source;
always @(*) begin
	case(transfer_idx)
		1: transfer_source <= Y;
		2: transfer_source <= A;
		4: transfer_source <= X;
		5: transfer_source <= X;
		6: transfer_source <= A;
		7: transfer_source <= stack_ptr;
		default: transfer_source <= A;
	endcase
end
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

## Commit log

2023-07-06 Initial commit: hardware.
    [6507-minicomp.kicad_pcb, 6507-minicomp.kicad_sch, 6507_expansion_board.kicad_pcb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]
2023-07-06 Verilog and Programs
    [tholin_6507.cfg]
